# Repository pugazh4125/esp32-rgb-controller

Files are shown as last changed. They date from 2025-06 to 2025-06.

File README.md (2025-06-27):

3D_view
# ESP32 RGB Controller

A custom-designed Bluetooth RGB LED strip controller using the **ESP32-WROOM** module.  
This project is part of my hardware design portfolio under the brand **Serially Wired**.

## 🔧 Features

- **Wireless Control via BLE** using ESP32
- Drives **12V RGB LED Strips** using IRLZ44N MOSFETs
- **Dual Power Input**:
  - USB-C (5V)
  - DC Barrel Jack (12V)
- Onboard **LD1117 3.3V Linear Regulator**
- **CH340N USB-to-Serial Interface** for easy programming
- **Logic Level Shifting** between 5V UART and 3.3V ESP32
- **Onboard LED indicators** for power and status
- Clean silkscreen labels, antenna keepout respected
- Designed in **KiCad** with ERC and DRC error-free

Feel Free to modify or collabrate with me in the project

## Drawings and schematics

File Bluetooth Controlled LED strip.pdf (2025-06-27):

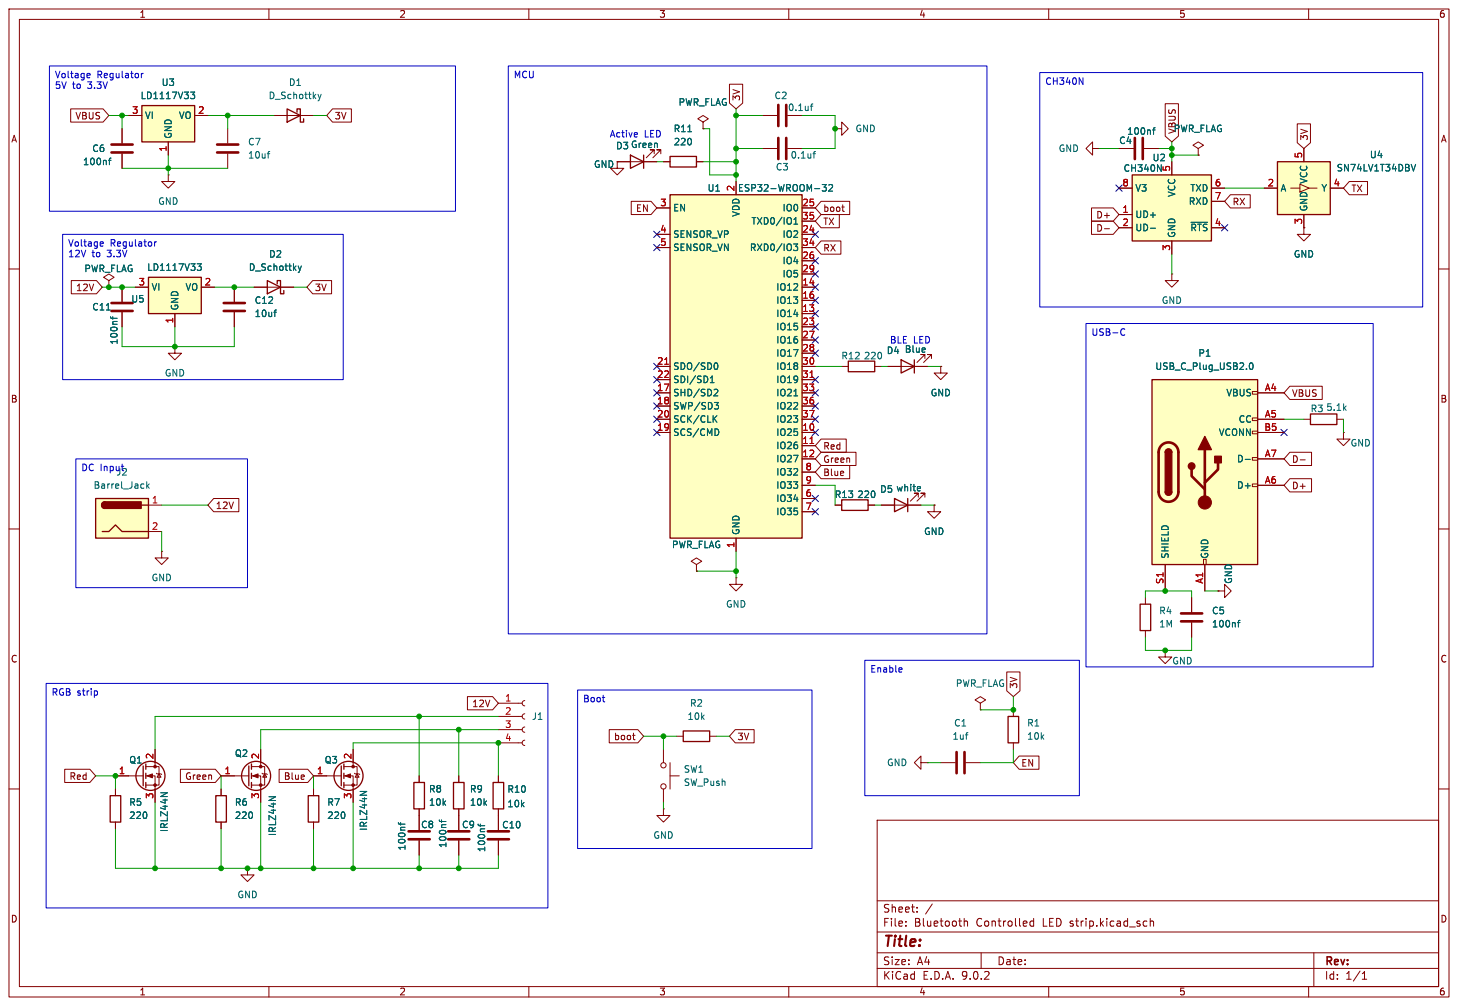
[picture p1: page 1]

3 TXD 6 RXD 7 ~{RTS}4 U2 CH340N GND

2 3 Q3 IRLZ44N SHIELD S1 GND A1 VBUS A4 CC A5 VCONN B5 D- A7 D+ A6 P1 USB_C_Plug_USB2.0 GND GND

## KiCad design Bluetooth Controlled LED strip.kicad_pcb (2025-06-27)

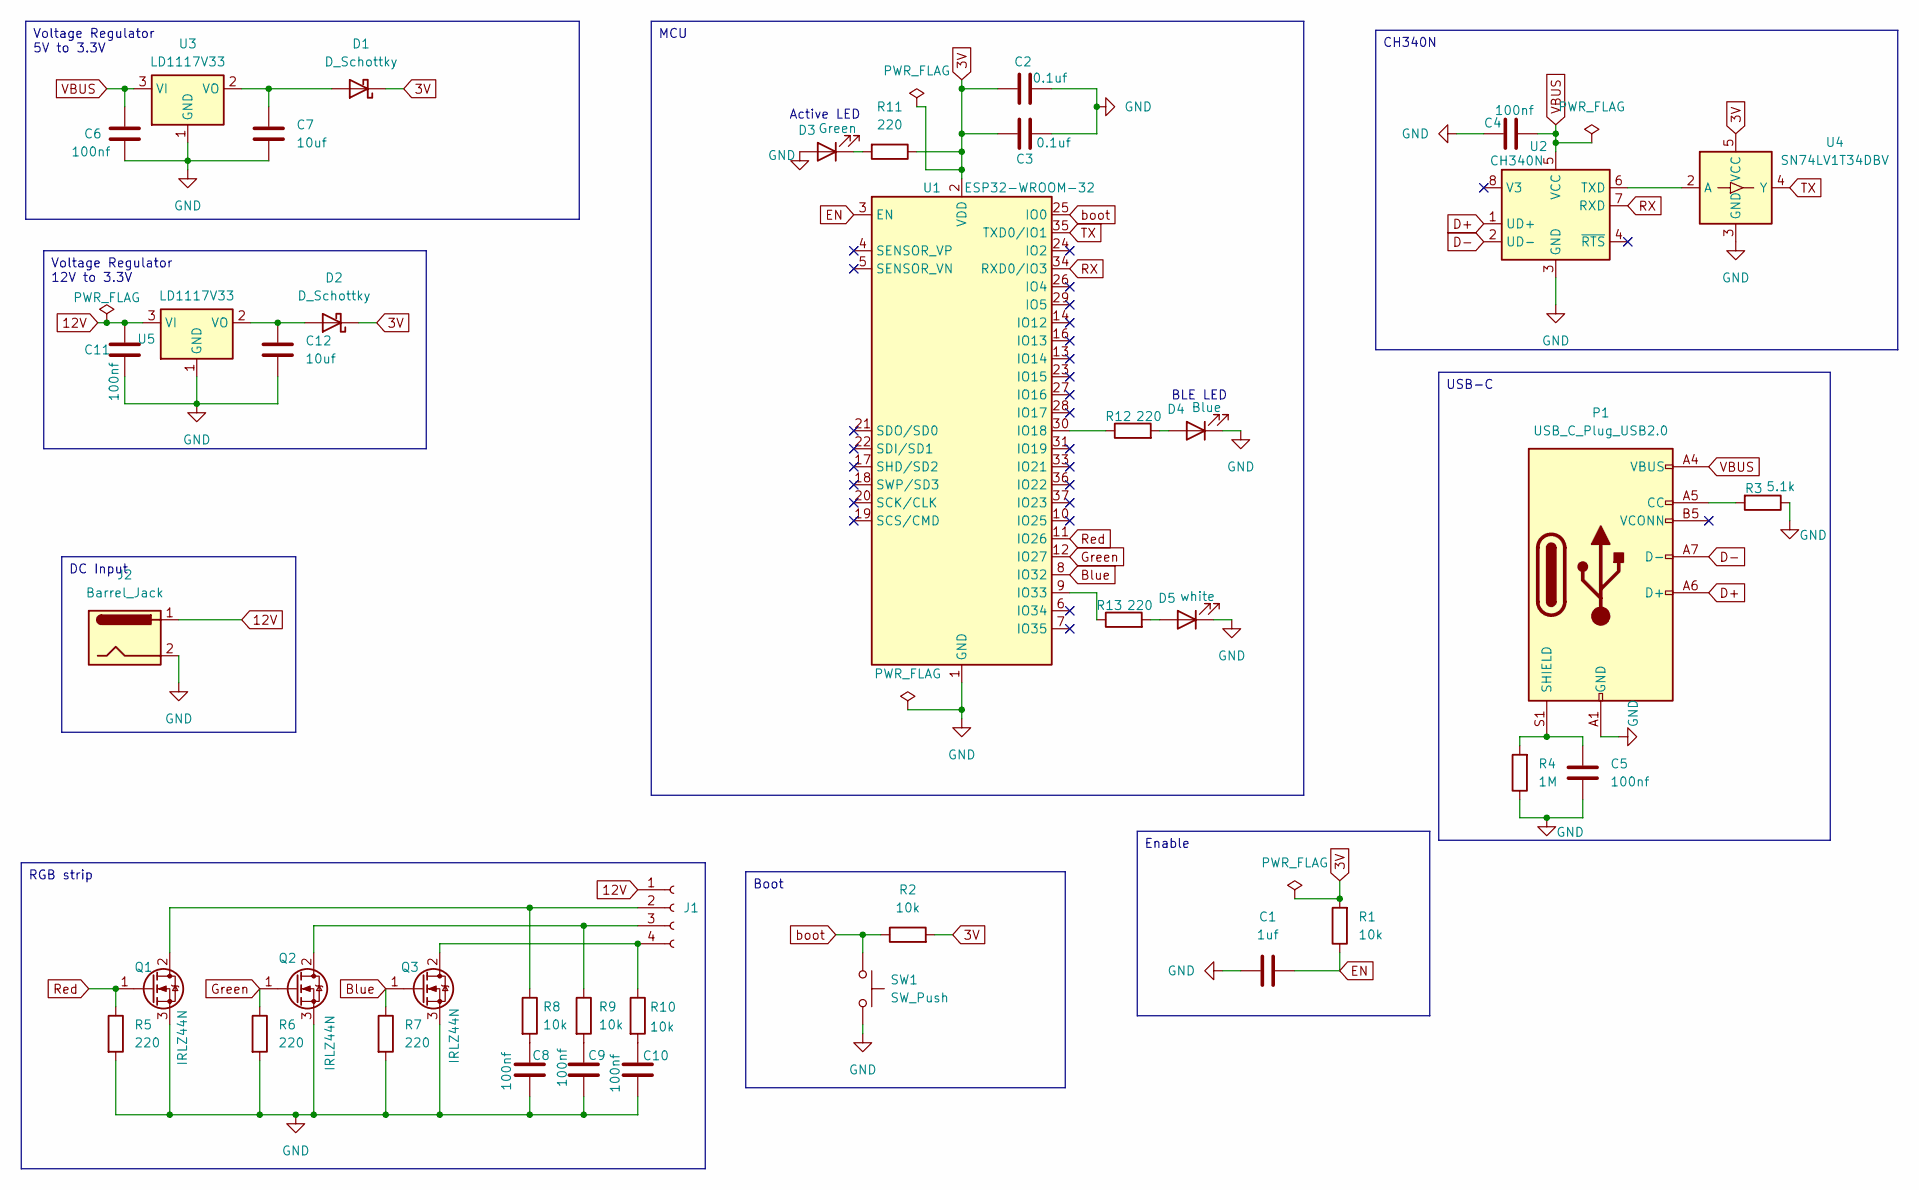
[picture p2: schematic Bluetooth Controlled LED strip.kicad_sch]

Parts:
C1: 1uf; C_0603_1608Metric
C2, C3: 0.1uf; C_0603_1608Metric
C4, C5, C6, C8, C9, C10, C11: 100nf; C_0603_1608Metric
C7, C12: 10uf; C_0603_1608Metric
D1, D2: D_Schottky; D_DO-41_SOD81_P10.16mm_Horizontal
D3: Green; LED_0603_1608Metric
D4: Blue; LED_0603_1608Metric
D5: white; LED_0603_1608Metric
J1: Conn_01x04_Socket; PinSocket_1x04_P2.54mm_Vertical
J2: Barrel_Jack; BarrelJack_Wuerth_694108106102_2.5x5.5mm
P1: USB_C_Plug_USB2.0; USB_C_Plug_JAE_DX07P024AJ1
Q1, Q2, Q3: IRLZ44N; TO-220-3_Vertical
R1, R2, R8, R9, R10: 10k; R_Axial_DIN0207_L6.3mm_D2.5mm_P10.16mm_Horizontal
R3: 5.1k; R_Axial_DIN0207_L6.3mm_D2.5mm_P10.16mm_Horizontal
R4: 1M; R_Axial_DIN0207_L6.3mm_D2.5mm_P10.16mm_Horizontal
R5, R6, R7, R11, R12, R13: 220; R_Axial_DIN0207_L6.3mm_D2.5mm_P10.16mm_Horizontal
SW1: SW_Push; SW_PUSH_6mm_H5mm
U1: ESP32-WROOM-32
U2: CH340N; SOP-8_3.9x4.9mm_P1.27mm
U3, U5: LD1117V33; TO-220-3_Vertical
U4: SN74LV1T34DBV; SOT-23-5

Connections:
3V: C2.1, C3.1, D1.1 (K), D2.1 (K), R1.2, R2.2, R11.1, U1.2 (VDD), U4.5 (VCC)
12V: C11.1, J1.1, J2.1, U5.3 (VI)
Blue: Q3.1 (G), R7.1, U1.8 (IO32)
D+: P1.A6 (D+), U2.1 (UD+)
D-: P1.A7 (D-), U2.2 (UD-)
EN: C1.2, R1.1, U1.3 (EN)
GND: C1.1, C2.2, C3.2, C4.1, C5.2, C6.2, C7.2, C8.2, C9.2, C10.2, C11.2, C12.2, D3.2 (A), D4.1 (K), D5.1 (K), J2.2, P1.A1 (GND), P1.A12 (GND), P1.B1 (GND), P1.B12 (GND), Q1.3 (S), Q2.3 (S), Q3.3 (S), R3.1, R4.1, R5.2, R6.2, R7.2, SW1.2, U1.1 (GND), U1.15 (GND), U1.38 (GND), U1.39 (GND), U2.3 (GND), U3.1 (GND), U4.3 (GND), U5.1 (GND)
Green: Q2.1 (G), R6.1, U1.12 (IO27)
unnamed: C8.1, R8.2
unnamed: C9.1, R9.2
unnamed: C10.1, R10.2
unnamed: C7.1, D1.2 (A), U3.2 (VO)
unnamed: C12.1, D2.2 (A), U5.2 (VO)
unnamed: D3.1 (K), R11.2
unnamed: D4.2 (A), R12.2
unnamed: D5.2 (A), R13.2
unnamed: J1.2, Q1.2 (D), R8.1
unnamed: J1.3, Q2.2 (D), R9.1
unnamed: J1.4, Q3.2 (D), R10.1
unnamed: P1.A5 (CC), R3.2
unnamed: C5.1, P1.S1 (SHIELD), R4.2
unnamed: R12.1, U1.30 (IO18)
unnamed: R13.1, U1.9 (IO33)
unnamed: U2.6 (TXD), U4.2 (A)
RX: U1.34 (RXD0/IO3), U2.7 (RXD)
Red: Q1.1 (G), R5.1, U1.11 (IO26)
TX: U1.35 (TXD0/IO1), U4.4 (Y)
VBUS: C4.2, C6.1, P1.A4 (VBUS), P1.A9 (VBUS), P1.B4 (VBUS), P1.B9 (VBUS), U2.5 (VCC), U3.3 (VI)
boot: R2.1, SW1.1, U1.25 (IO0)

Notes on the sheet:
Active LED
BLE LED
CH340N
RGB strip
DC Input
Boot
Voltage Regulator 5V to 3.3V
Enable
MCU
Voltage Regulator 12V to 3.3V
USB-C

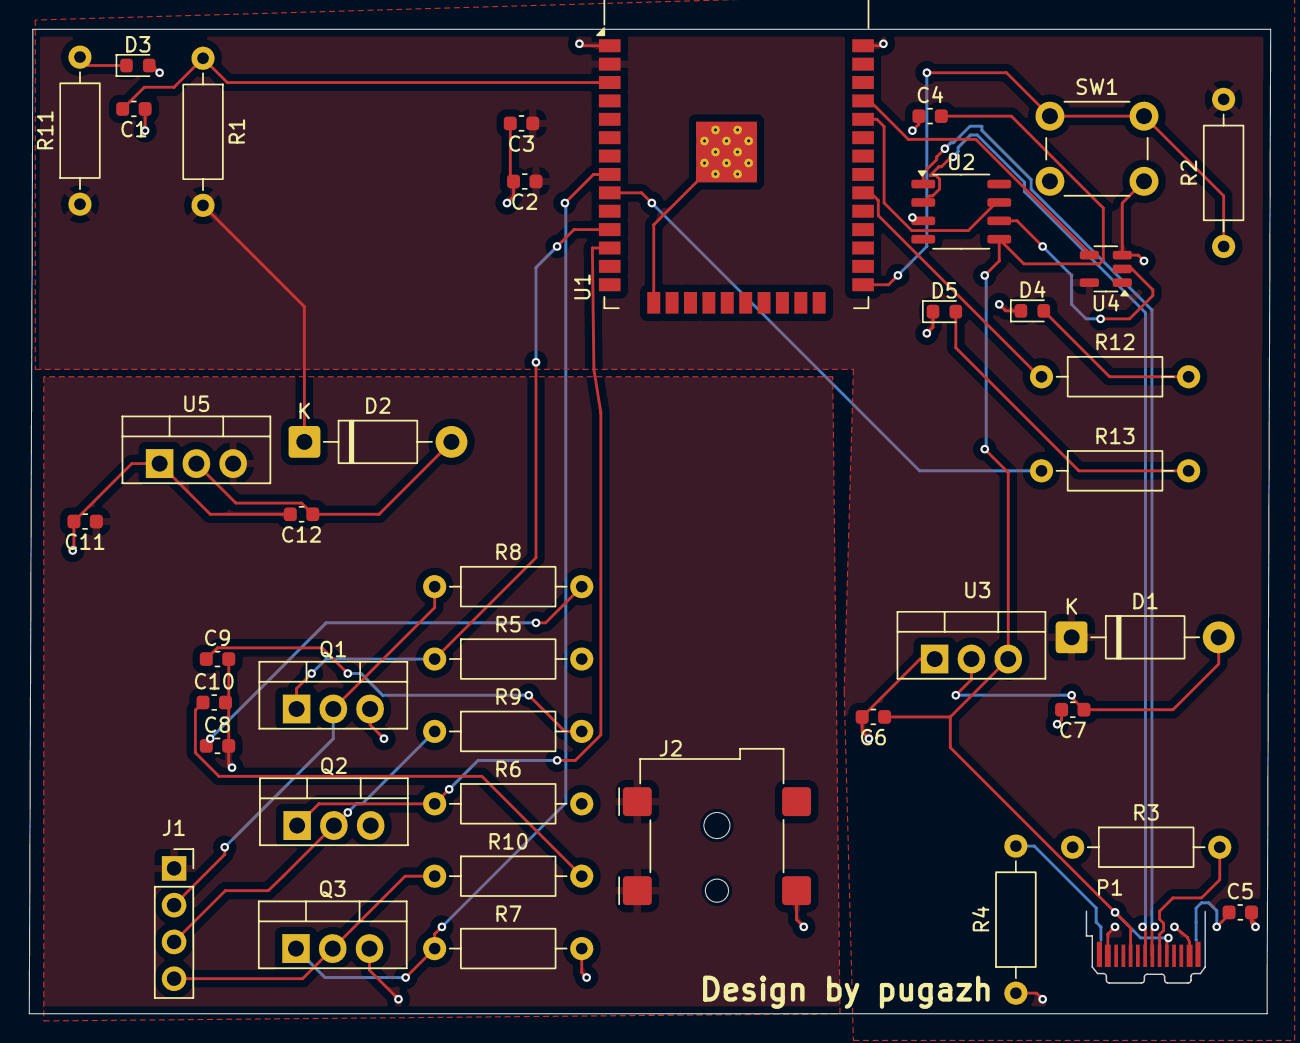
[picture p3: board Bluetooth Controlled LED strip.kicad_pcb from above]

Board: 2 copper layers, 85.8 x 68.0 mm, 42 parts (0 on the bottom side), 29 nets.
